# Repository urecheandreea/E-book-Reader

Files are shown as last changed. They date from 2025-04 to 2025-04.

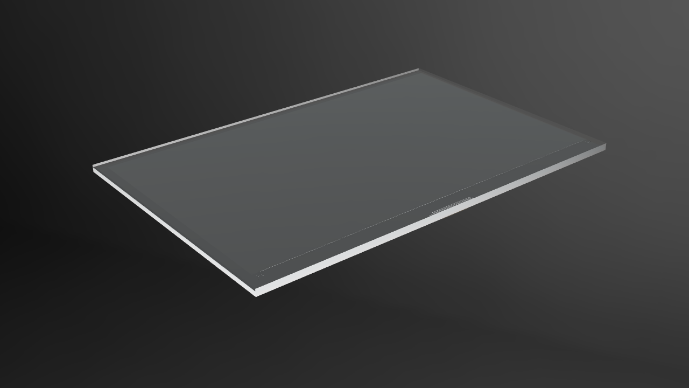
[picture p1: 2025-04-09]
Images/Display.png

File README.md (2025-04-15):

# E-book-Reader
## Hardware 
**OpenBook** is an open-source, portable e-reader powered by the **ESP32-C6-WROOM-1-N8** microcontroller.
### Microcontroller - **ESP32-C6-WROOM-1-N8**
  - 32-bit RISC-V @ 160 MHz
  - 8MB internal flash
  - Supports **Wi-Fi 6 (802.11ax)** and **Bluetooth 5.0 LE**
  - Interfaces used:
    - **SPI** (for E-Ink display, Flash, SD card)
    - **I2C** (for sensors and RTC)
    - **UART**, **GPIO**, **PWM**
### E-Ink Display
- **E-Ink screen** connected via SPI:
  - MOSI: GPIO18  
  - MISO: GPIO19  
  - CLK: GPIO20  
  - CS: GPIO21  
- Power is controlled via MOSFET (Q3 - S1B126DT1-GE3) to save energy.
- Display type selection is done via jumper (S11, P2).
##  Storage
- **MicroSD Card**
  - Connected via SPI (CS: GPIO9)
  - Used for storing files and data logging
- **NOR Flash – W25Q512JVEIQ**
  - 64MB external flash via SPI
##  Sensors
- **BME688** – Measures temperature, pressure, humidity, and air quality  
- **DS3231SN** – High-precision Real-Time Clock (RTC)  
- **MAX17048G+T10** – Battery fuel gauge (State of Charge)
- All sensors are connected via the **I2C** bus:
  - SDA: GPIO6  
  - SCL: GPIO7  
##  Power Management
- **USB-C connector**
  - Used for charging and possible data transfer
  - Includes CC identification and ESD protection
- **MCP73831** – LiPo battery charging IC
- **XC6220A331MR-G** – Low dropout regulators for 3.3V power
- EPD and I2C power rails are individually controlled via MOSFETs
- ESD protection on USB and SPI lines (USBLC6-2SC6Y, SD05B05V2L)
## Interfaces & Expandability
- **QWIIC / Stemma QT connector**
  - Easy expansion via plug-and-play I2C modules
- **Test Pads**
  - Breakout access to GPIO, UART, I2C for debugging
- **Control buttons**
  - RESET and BOOT
- **Status LEDs** for user feedback

## Power Consumption Summary
| Component | Active (mA) | Sleep (mA) | Notes |
|---|---|---|---|
| **ESP32-C6** | ~80–100 | ~0.02 | Depends on Wi-Fi & sleep mode |
| **E-Paper Display** | ~26 | ~0.01 | Only during refresh |
| **BME688 Sensor** | ~2.1 | ~0.15 | Sleep mode available |
| **RTC DS3231** | ~0.2 | ~0.2 | Constant low power |
| **MicroSD Card** | ~30–100 | ~0.2 | Depends on access frequency |
| **W25Q512JVEIQ Flash**| ~10–20 | ~0.01 | During SPI read/write |
## ESP32-C6 Pin Usage
| Component | ESP32-C6 Pin(s) | Interface | Purpose |
|---|---|---|---|
| E-Paper Display | GPIO7 (MOSI), GPIO6 (SCK), GPIO10 (CS), GPIO5 (DC), GPIO23 (RST), GPIO3 (BUSY) | SPI | Transfers image data to the display and controls its state |
| MicroSD Card | GPIO7 (MOSI), GPIO6 (SCK), GPIO4 (CS_SD), GPIO2 (MISO) | SPI | Allows storage and retrieval of e-book files |
| BME688 Sensor | GPIO21 (SDA), GPIO22 (SCL) | I2C | Reads temperature, humidity, pressure, and air quality |
| RTC Module (DS3231) | GPIO21 (SDA), GPIO22 (SCL), GPIO18 (RST), GPIO1 (32KHz, optional), GPIO0 (INT_RTC, optional) | I2C | Keeps track of time even when the ESP32 is off |
| NOR Flash (W25Q512J) | GPIO11 (CS_FLASH), GPIO6 (SCK), GPIO2 (MISO), GPIO7 (MOSI) | SPI | Additional non-volatile storage |
| Battery Fuel Gauge | GPIO21 (SDA), GPIO22 (SCL) | I2C | Monitors battery level and charge status |
| USB-C Connector | Via LDO regulator to 3.3V power rail | USB | Supplies power and programming interface for the ESP32-C6 |
| Control Buttons | GPIO9 (BOOT), GPIO15 (CHANGE), EN (RESET) | GPIO | User input for device interaction and hardware reset |

## Block Diagram
Diagram

## Bill Of Materials
| Component | Link | Datasheet |
|---|---|---|
| ESP32-C6-WROOM-1-N8 | [SnapEDA](https://www.snapeda.com/parts/ESP32-C6-WROOM-1-N8/Espressif+Systems/view-part/?ref=eda) | [Datasheet](https://www.snapeda.com/parts/ESP32-C6-WROOM-1-N8/Espressif%20Systems/datasheet/) |
| MCP73831T-2ACI/OT – PMIC | [SnapEDA](https://www.snapeda.com/parts/MCP73831T-2ACI/OT/Microchip/datasheet/) | [Datasheet](https://www.snapeda.com/parts/MCP73831T-2ACI/OT/Microchip/datasheet/) |
| MAX17048G+T10 – Fuel Gauge | [SnapEDA](https://www.snapeda.com/parts/MAX17048G+T10/Analog+Devices/view-part/?ref=eda) | [Datasheet](https://www.snapeda.com/parts/MAX17048G+T10/Analog%20Devices/datasheet/) |
| BME680 – Environmental Sensor | [SnapEDA](https://www.snapeda.com/parts/BME680/Bosch/view-part/?welcome=home) | [Datasheet](https://www.bosch-sensortec.com/media/boschsensortec/downloads/datasheets/bst-bme680-ds001.pdf) |
| DS3231SN – RTC | [SnapEDA](https://www.snapeda.com/parts/DS3231SN%23/Analog+Devices/view-part/?ref=eda) | [Datasheet](https://www.snapeda.com/parts/DS3231SN%23/Analog%20Devices/datasheet/) |
| W25Q512JVEIQ – SPI Flash | [SnapEDA](https://www.snapeda.com/parts/W25Q512JVEIQ/Winbond+Electronics/view-part/?ref=eda) | [Datasheet](https://www.winbond.com/resource-files/W25Q512JV%20SPI%20RevB%2006252019%20KMS.pdf) |
| QWIIC Connector | [SnapEDA](https://www.snapeda.com/parts/PRT-14417/SparkFun/view-part/) | [Datasheet](https://www.snapeda.com/parts/PRT-14417/SparkFun%20Electronics/datasheet/) |
| USB4110-GF-A – USB-C Connector | [ComponentSearchEngine](https://componentsearchengine.com/part-view/USB4110-GF-A/GCT%20(GLOBAL%20CONNECTOR%20TECHNOLOGY)) | [Datasheet](https://gct.co/files/drawings/usb4110.pdf) |
| FH34SRJ-24S-0.5SH – FFC Connector | [Mouser](https://ro.mouser.com/ProductDetail/Hirose-Connector/FH34SRJ-24S-0.5SH99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) | [Datasheet](https://www.snapeda.com/parts/FH34SRJ-24S-0.5SH(99)/Hirose%20Connector/datasheet/) |
| KP-1608SURCK – LED 0603 | [SnapEDA](https://www.snapeda.com/parts/KP-1608SURCK/Kingbright/view-part/?ref=search&t=LED%200603) | [Datasheet](https://www.snapeda.com/parts/KP-1608SURCK/Kingbright/datasheet/) |
| EVQPUJ02K – Custom Button | [Panasonic](https://industry.panasonic.com/global/en/products/control/switch/light-touch/number/evqpuj02k) | [Datasheet](https://industry.panasonic.com/global/en/downloads?tab=catalog&small_g_cd=203&part_no=EVQPUJ02K) |
| CPH3225A – RTC Crystal | [SnapEDA](https://www.snapeda.com/parts/CPH3225A/Seiko+Instruments/view-part/?ref=snap) | [Datasheet](https://www.snapeda.com/parts/CPH3225A/Seiko%20Instruments/datasheet/) |
| BD5229G-TR – Reset IC | [ComponentSearchEngine](https://componentsearchengine.com/part-view/BD5229G-TR/ROHM%20Semiconductor) | [Datasheet](https://fscdn.rohm.com/en/products/databook/datasheet/ic/power/voltage_detector/bd52xxg-e.pdf) |
| XC6220A331MR-G – LDO Regulator | [ComponentSearchEngine](https://componentsearchengine.com/part-view/XC6220A331MR-G/Torex) | [Datasheet](https://product.torexsemi.com/system/files/series/xc6220.pdf) |
| 744043680 – Inductor | [Mouser](https://ro.mouser.com/ProductDetail/Wurth-Elektronik/744043680?qs=PGXP4M47uW6VkZq%252BkzjrHA%3D%3D) | [Datasheet](https://www.we-online.com/components/products/datasheet/744043680.pdf) |
| SI1308EDL – MOSFET | [SnapEDA](https://www.snapeda.com/parts/SI1308EDL-T1-GE3/Vishay+Siliconix/view-part/?welcome=home&ref=eda) | [Datasheet](https://www.snapeda.com/parts/SI1308EDL-T1-GE3/Vishay%20Siliconix/datasheet/) |
| MBR0530 – Schottky Diode | [SnapEDA](https://www.snapeda.com/parts/MBR0530/Onsemi/view-part/?ref=snap) | [Datasheet](https://www.snapeda.com/parts/MBR0530/ON%20Semiconductor/datasheet/) |
| USBLC6-2SC6Y – ESD Protection | [SnapEDA](https://www.snapeda.com/parts/USBLC6-2SC6Y/STMicroelectronics/view-part/?welcome=home&ref=eda) | [Datasheet](https://www.snapeda.com/parts/USBLC6-2SC6Y/STMicroelectronics/datasheet/) |
| PGB1010603MR – TVS Protection | [SnapEDA](https://www.snapeda.com/parts/PGB1010603MR/Littelfuse/view-part/?ref=eda) | [Datasheet](https://www.snapeda.com/parts/PGB1010603MR/Littelfuse%20Inc./datasheet/) |
| 112A-TAAR-R03 – Pin Header | [Comet](https://store.comet.srl.ro/Catalogue/Product/43497/) | [Datasheet](https://www.snapeda.com/parts/112A-TAAR-R03/Attend/datasheet/) |
| 0402 Ceramic Capacitor | [Mouser](https://ro.mouser.com/c/passive-components/capacitors/ceramic-capacitors/?q=CC0402) | [Datasheet](https://componentsearchengine.com/Datasheets/2/CC0402MRX5R5BB106.pdf) |
| 0402 Resistor | [GrabCAD](https://grabcad.com/library/resistor-0402-1) | [Datasheet](https://www.yageo.com/upload/media/product/products/datasheet/rchip/PYu-RC_Group_51_RoHS_L_12.pdf) |
| TAJB475K025RNJ – 3528 Tantalum Cap | [SnapEDA](https://www.snapeda.com/parts/TAJB475K025RNJ/AVX%20Corporation/view-part/?ref=eda) | [Datasheet](https://s3.amazonaws.com/snapeda/datasheet/TAJB475K025RNJ_AVX.pdf) |
| SJ -SMD solder JUMPER | [GrabCAD](https://grabcad.com/library/solder-jumpers-1) | [DataSheet](https://www.farnell.com/datasheets/2813407.pdf) |
| PFMF.050.1-ESP32C6_VARISTORCN1812  | [Mouser](https://www.mouser.co.uk/ProductDetail/EPCOS-TDK/B72520T0350K062?qs=dEfas%2FXlABIszF52uu7vrg%3D%3D)| [DataSheet](https://www.tdk-electronics.tdk.com/inf/75/db/CTVS_14/Surge_protection_series.pdf)  | 

## Implementation Steps
Creating the schematic according to the diagram,Finding and loading 3D models for each component,Designing the PCB,Placing the components on the PCB,Routing,Creating ground planes, via-stitching,Meeting requirements (component names on top silkscreen, DRC clean, etc.),Creating the battery and display,Assembling everything into the enclosure.

I only approved the "SMD-Hole, Board Outline Clearance" errors, as this was previously accepted and specified.

## Issues encountered:
I had to manually add the 3D model for EACH component because I had problems and errors when trying to update the library (adding to the library wasn't working), which was extremely time-consuming.

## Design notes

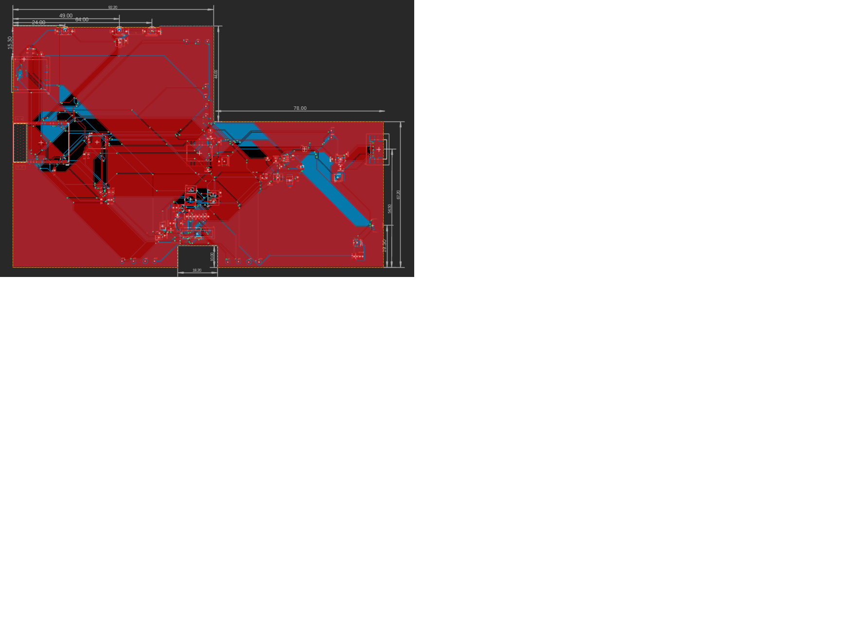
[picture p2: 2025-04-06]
Images/PCB1.png

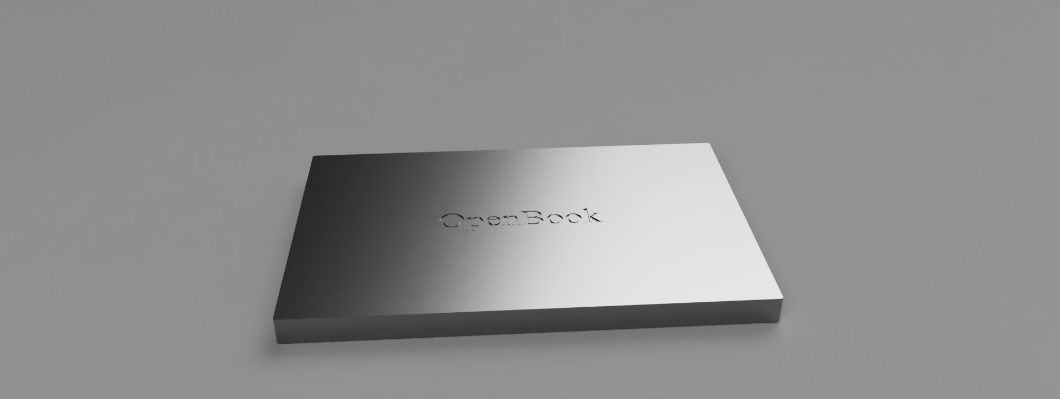
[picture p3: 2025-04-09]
Images/Render.png

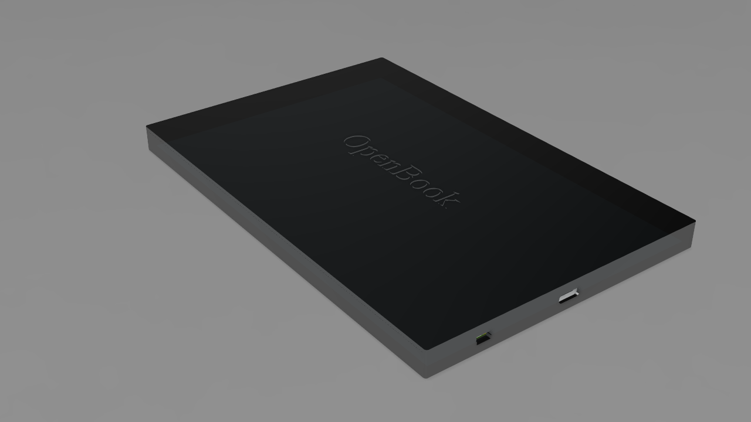
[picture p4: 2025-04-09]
Images/TopView.png

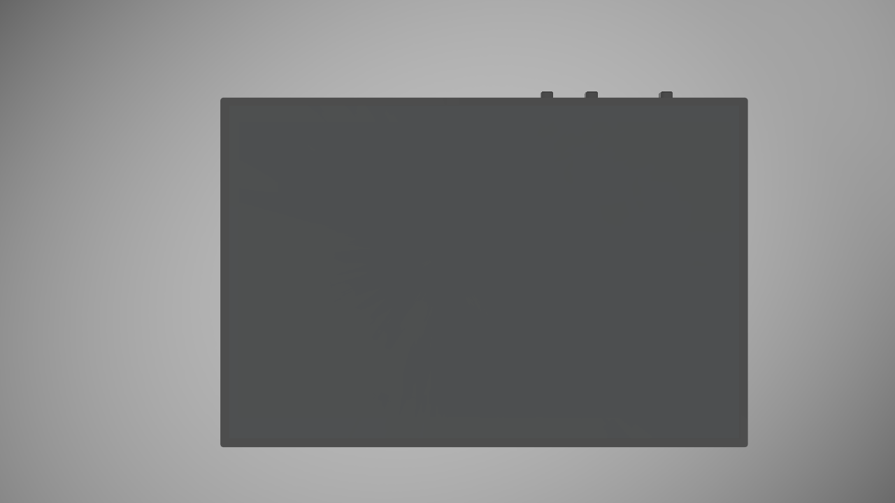
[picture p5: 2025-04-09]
Images/bottomView.png

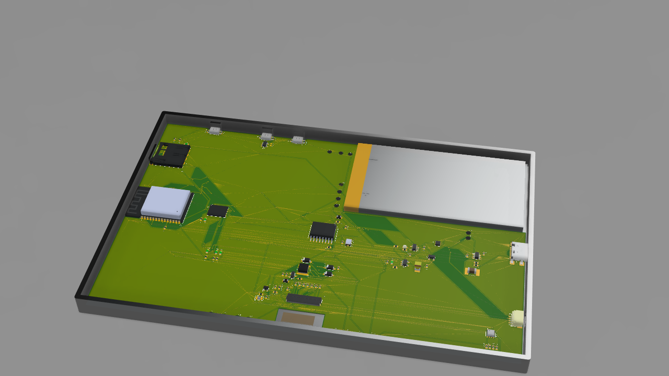
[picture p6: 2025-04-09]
Images/InteriorView.png

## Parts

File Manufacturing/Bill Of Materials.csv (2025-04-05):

Qty | Value | Device | Package | Parts | Description | ARROW_PART_NUMBER | ARROW_PRICE-STOCK | AVAILABILITY | CENTROID_NOT_SPECIFIED | CHECK_PRICES | COPYRIGHT | DATASHEET | DESCRIPTION | DIGIKEY_DESCRIPTION | DIGIKEY_PART_NUMBER | HEIGHT | LEAD_FREE | MANUFACTURER_NAME | MANUFACTURER_PART_NUMBER | MF | MFR_NAME | MOUSER_PART_NUMBER | MOUSER_PRICE-STOCK | MOUSER_TESTING_PART_NUMBER | MOUSER_TESTING_PRICE-STOCK | MP | MPN | PACKAGE | POPULARITY | PREFIX | PRICE | PROD_ID | PURCHASE-URL | ROHS | SNAPEDA_LINK | SPICEMODEL | SPICEPREFIX | TEMPERATURE_RANGE_HIGH | TEMPERATURE_RANGE_LOW | TP_SIGNAL_NAME | VALUE
1 |  | ADAFRUIT_LEDCHIP-LED0603 | ADAFRUIT_CHIP-LED0603 | CHG_LED | LED
1 |  | ESP32_WROVER_SPARKFUN-IC-POWER_MCP73831 | ESP32_WROVER_SPARKFUN-IC-POWER_SOT23-5 | MCP73831 | MCP73831T Li-Ion, Li-Pol Controller |  |  |  |  |  |  |  |  |  |  |  |  |  |  |  |  |  |  |  |  |  |  |  |  |  |  | IC-09995
1 |  | SJ | SJ | SJ1 | SMD solder JUMPER |  |  |  |  |  |  |  |  |  |  |  |  |  |  |  |  |  |  |  |  |  |  |  | 3
1 | 0.1uF/50V | ESP32_WROVER_EAGLE-LTSPICE_CC0402 | ESP32_WROVER_EAGLE-LTSPICE_C0402 | EPD_C5 | CAPACITOR, European symbol |  |  |  |  |  |  |  |  |  |  |  |  |  |  |  |  |  |  |  |  |  |  |  |  |  |  |  |  |  |  | NONE | C
1 | 0.47 | ESP32_WROVER_EAGLE-LTSPICE_RR0402 | ESP32_WROVER_EAGLE-LTSPICE_R0402 | R3 | RESISTOR, European symbol |  |  |  |  |  |  |  |  |  |  |  |  |  |  |  |  |  |  |  |  |  |  |  |  |  |  |  |  |  |  | NONE | R
1 | 100k | ESP32_WROVER_EAGLE-LTSPICE_RR0402 | ESP32_WROVER_EAGLE-LTSPICE_R0402 | R1_PWRUSB | RESISTOR, European symbol |  |  |  |  |  |  |  |  |  |  |  |  |  |  |  |  |  |  |  |  |  |  |  |  |  |  |  |  |  |  | NONE | R
6 | 100nF | EAGLE-LTSPICE_CC0402 | EAGLE-LTSPICE_C0402 | C1, C2, C6, C9, C10, C_DELAY | CAPACITOR, European symbol |  |  |  |  |  |  |  |  |  |  |  |  |  |  |  |  |  |  |  |  |  |  |  |  |  |  |  |  |  |  | NONE | C
2 | 100nF | ESP32_WROVER_EAGLE-LTSPICE_CC0402 | ESP32_WROVER_EAGLE-LTSPICE_C0402 | C4_USB, C8 | CAPACITOR, European symbol |  |  |  |  |  |  |  |  |  |  |  |  |  |  |  |  |  |  |  |  |  |  |  |  |  |  |  |  |  |  | NONE | C
1 | 100uF TANT | RCL_CPOL-EUCT3528 | RCL_CT3528 | C3 | POLARIZED CAPACITOR, European symbol |  |  |  |  |  |  |  |  |  |  |  |  |  |  |  |  |  |  |  |  |  |  |  | 0 |  |  |  |  |  |  |  | C
16 | 10K | ESP32_WROVER_EAGLE-LTSPICE_RR0402 | ESP32_WROVER_EAGLE-LTSPICE_R0402 | R1, R1_PINH, R1_PINH1, R2-PINH, R2-PINH1, R4, R5, R6, R7, R8, R9, R10, R_BOOT, R_CHANGE, R_CL1, R_RESET | RESISTOR, European symbol |  |  |  |  |  |  |  |  |  |  |  |  |  |  |  |  |  |  |  |  |  |  |  |  |  |  |  |  |  |  | NONE | R
1 | 10uF | ESP32_WROVER_EAGLE-LTSPICE_CC0402 | ESP32_WROVER_EAGLE-LTSPICE_C0402 | C7 | CAPACITOR, European symbol |  |  |  |  |  |  |  |  |  |  |  |  |  |  |  |  |  |  |  |  |  |  |  |  |  |  |  |  |  |  | NONE | C
1 | 112A-TAAR-R03_ATTEND | 112A-TAAR-R03_ATTEND | 112ATAARR03ATTEND | J4 | Micro SD Card Socket, Push-Push Type, Top Mount, SMT, H=1.83mm, 10u |  |  |  |  |  |  |  | Micro SD Card Socket | Push-Push Type | Top Mount | SMT | H=1.83mm | 10u |  |  | 1.9mm |  | ATTEND | 112A-TAAR-R03 ATTEND
1 | 15 | ESP32_WROVER_EAGLE-LTSPICE_RR0402 | ESP32_WROVER_EAGLE-LTSPICE_R0402 | R_CAPACITOR | RESISTOR, European symbol |  |  |  |  |  |  |  |  |  |  |  |  |  |  |  |  |  |  |  |  |  |  |  |  |  |  |  |  |  |  | NONE | R
1 | 1uF | EAGLE-LTSPICE_CC0402 | EAGLE-LTSPICE_C0402 | C5 | CAPACITOR, European symbol |  |  |  |  |  |  |  |  |  |  |  |  |  |  |  |  |  |  |  |  |  |  |  |  |  |  |  |  |  |  | NONE | C
9 | 1uF/50V | ESP32_WROVER_EAGLE-LTSPICE_CC0402 | ESP32_WROVER_EAGLE-LTSPICE_C0402 | EPD_C1, EPD_C2, EPD_C6, EPD_C7, EPD_C8, EPD_C9, EPD_C10, EPD_C11, EPD_C12 | CAPACITOR, European symbol |  |  |  |  |  |  |  |  |  |  |  |  |  |  |  |  |  |  |  |  |  |  |  |  |  |  |  |  |  |  | NONE | C
1 | 2.2 | ESP32_WROVER_EAGLE-LTSPICE_RR0402 | ESP32_WROVER_EAGLE-LTSPICE_R0402 | R2 | RESISTOR, European symbol |  |  |  |  |  |  |  |  |  |  |  |  |  |  |  |  |  |  |  |  |  |  |  |  |  |  |  |  |  |  | NONE | R
1 | 200 | ESP32_WROVER_EAGLE-LTSPICE_RR0402 | ESP32_WROVER_EAGLE-LTSPICE_R0402 | R1_BAT | RESISTOR, European symbol |  |  |  |  |  |  |  |  |  |  |  |  |  |  |  |  |  |  |  |  |  |  |  |  |  |  |  |  |  |  | NONE | R
2 | 20V/4.2A/52mO/1.4W | ESP32_WROVER_SPARKFUN-DISCRETESEMI_MOSFET_PCH-DMG2305UX-7 | ESP32_WROVER_SPARKFUN-DISCRETESEMI_SOT23-3 | Q1, Q2 | P-channel MOSFETs |  |  |  |  |  |  |  |  |  |  |  |  |  |  |  |  |  |  |  |  |  |  |  |  |  |  | TRAN-14388 |  |  |  |  |  |  |  |  | 20V/4.2A/52mO/1.4W
1 | 2K | ESP32_WROVER_EAGLE-LTSPICE_RR0402 | ESP32_WROVER_EAGLE-LTSPICE_R0402 | R2_BAT | RESISTOR, European symbol |  |  |  |  |  |  |  |  |  |  |  |  |  |  |  |  |  |  |  |  |  |  |  |  |  |  |  |  |  |  | NONE | R
5 | 4.7uF | EAGLE-LTSPICE_CC0402 | EAGLE-LTSPICE_C0402 | C1_BAT, C1_BAT1, C1_BAT2, C2_BAT, C5_USB | CAPACITOR, European symbol |  |  |  |  |  |  |  |  |  |  |  |  |  |  |  |  |  |  |  |  |  |  |  |  |  |  |  |  |  |  | NONE | C
1 | 4.7uF/25V | ESP32_WROVER_EAGLE-LTSPICE_CC0402 | ESP32_WROVER_EAGLE-LTSPICE_C0402 | C4 | CAPACITOR, European symbol |  |  |  |  |  |  |  |  |  |  |  |  |  |  |  |  |  |  |  |  |  |  |  |  |  |  |  |  |  |  | NONE | C
2 | 5k1 | ESP32_WROVER_EAGLE-LTSPICE_RR0402 | ESP32_WROVER_EAGLE-LTSPICE_R0402 | R2-USB, R2-USB1 | RESISTOR, European symbol |  |  |  |  |  |  |  |  |  |  |  |  |  |  |  |  |  |  |  |  |  |  |  |  |  |  |  |  |  |  | NONE | R
1 | 68uH | 744043680IND_4828-WE-TPC_WRE | IND_4828-WE-TPC_WRE | L1 |  |  |  |  |  |  | Copyright (C) 2024 Ultra Librarian. All rights reserved. |  |  |  |  |  |  |  | 744043680 |  | Wurth Electronics
1 | BD5229G-TR | BD5229G-TR | SOT95P280X125-5N | IC1 | Voltage Detector with Adjustable Delay Time: CMOS processes are utilized to develop high precision, low current consumption CMOS reset ICs that allow arbitrary setting of the delay time. The extensive lineup includes both Nch Open Drain and CMOS output types in a wide range of detection voltages (from 2.3V to 6.0V, in 0.1V steps), enabling selection of the ideal solution based on customer requirements. In addition, the entire series is of course both lead-free and RoHS-compliant. |  |  |  |  |  |  |  | Voltage Detector with Adjustable Delay Time: CMOS processes are utilized to develop high precision | low current consumption CMOS reset ICs that allow arbitrary setting of the delay time. The extensive lineup includes both Nch Open Drain and CMOS output types in a wide range of detection voltages (from 2.3V to 6.0V | in 0.1V steps) | enabling selection of the ideal solution based on customer requirements. In addition | the entire series is of course both lead-free and RoHS-compliant. |  |  | 1.25mm |  | ROHM Semiconductor | BD5229G-TR |  |  | 755-BD5229G-TR | https://www.mouser.co.uk/ProductDetail/ROHM-Semiconductor/BD5229G-TR?qs=4kLU8WoGk0vvnhrrYwdszw%3D%3D
1 | BME688 | ESP32_WROVER_BME680_BME680 | ESP32_WROVER_BME680_PSON80P300X300X100-8N | SENSOR2 | Integrated Environmental Unit |  |  | Unavailable |  |  |  |  | Integrated Environmental Unit |  |  |  |  |  |  | Bosch Sensortec |  |  |  |  |  | BME680 |  | LGA-8 Bosch Tools |  |  | None
1 | BOOT_BUTTON | BUTTON_CUSYOMV1 | MYBUTTON | BOOT_BUTTON
1 | CHANGE_BUTTON | BUTTON_CUSYOMV1 | MYBUTTON | CHANGE_BUTTON
1 | CPH3225A | CPH3225A | CAPCP3225X100N | C10_SUPERCAP | Cap 0.011F 3.3V 1210 Flat Check availability |  |  | Not in stock |  | https://www.snapeda.com/parts/CPH3225A/Seiko+Instruments/view-part/?ref=eda |  |  | 11 mF (EDLC) Supercapacitor 3.3 V 1210 (3225 Metric) - - |  |  |  |  |  |  | Seiko Instruments |  |  |  |  |  | CPH3225A |  | 1210 Seiko |  |  | None |  | https://www.snapeda.com/api/url_track_click_mouser/?unipart_id=562593&manufacturer=Seiko Instruments&part_name=CPH3225A&search_term=None |  | https://www.snapeda.com/parts/CPH3225A/Seiko+Instruments/view-part/?ref=snap
1 | DS3231SN# | DS3231SN# | SOIC127P1032X265-16N | U3 | Real Time Clock Serial 16-Pin SOIC W T/R Check availability |  |  | In Stock |  | https://www.snapeda.com/parts/DS3231SN%23/Analog+Devices/view-part/?ref=eda |  |  | Extremely Accurate I²C-Integrated RTC/TCXO/Crystal |  |  |  |  |  |  | Analog Devices |  |  |  |  |  | DS3231SN# |  | SOIC-16 Maxim |  |  | None |  | https://www.snapeda.com/api/url_track_click_mouser/?unipart_id=99048&manufacturer=Analog Devices&part_name=DS3231SN#&search_term=None |  | https://www.snapeda.com/parts/DS3231SN%23/Analog+Devices/view-part/?ref=snap
1 | ESP32-C6-WROOM-1-N8 | ESP32-C6-WROOM-1-N8 | XCVR_ESP32-C6-WROOM-1-N8 | U2 | Check availability |  |  | In Stock |  | https://www.snapeda.com/parts/ESP32-C6-WROOM-1-N8/Espressif+Systems/view-part/?ref=eda |  |  | Multiprotocol Modules ESP32-C6 module | Wi-Fi 6 in 2.4 GHz band | Bluetooth 5 | Zigbee 3.0 and Thread. ESP34-WROOM Compatible - ENGINEERING SAMPLE |  |  |  |  |  |  | Espressif Systems |  |  |  |  |  | ESP32-C6-WROOM-1-N8 |  | None |  |  | None |  |  |  | https://www.snapeda.com/parts/ESP32-C6-WROOM-1-N8/Espressif+Systems/view-part/?ref=snap
1 | ESP32C6_VARISTORCN1812 | ESP32C6_VARISTORCN1812 | ESP32C6_VARISTOR_CT/CN1812 | PFMF.050.1 | VARISTOR |  |  |  |  |  |  |  |  |  |  |  |  |  |  |  |  |  |  |  |  |  |  |  | 0
1 | ESP32_WROVER_AVX---SD0805S020S1R0_AVX_SD0805S020S1R0_0_0AVX_SD0805S020S1R0_0_0 | ESP32_WROVER_AVX---SD0805S020S1R0_AVX_SD0805S020S1R0_0_0AVX_SD0805S020S1R0_0_0 | ESP32_WROVER_AVX---SD0805S020S1R0_AVX_SD0805S020S1R0_0 | D2 | Schottky Barrier Rectifier Diode |  |  |  | No |  |  | http://datasheets.avx.com/schottky.pdf |  | DIODE SCHOTTKY 20V 1A 0805 | 478-7800-1-ND |  | yes |  |  | AVX |  | 581-SD0805S020S1R0 |  |  |  |  |  | 0805 (2012 metric) |  | D |  |  |  | yes |  |  |  | +125°C | -55°C
1 | FH34SRJ-24S-0.5SH_99_ | FH34SRJ-24S-0.5SH_99_ | FH34SRJ24S05SH99 | J1 | (0.50mm) Surface Mount, Right Angle |  |  |  |  |  |  |  | 24 Position FFC | FPC Connector Contacts | (0.50mm) Surface Mount | Right Angle |  |  | 1.1mm |  | Hirose | FH34SRJ-24S-0.5SH(99) |  |  | 798-FH34SRJ24S05SH99 | https://www.mouser.co.uk/ProductDetail/Hirose-Connector/FH34SRJ-24S-0.5SH99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
1 | MAX17048G+T10 | MAX17048G+T10 | SON50P200X200X80-9N | U4 | Check availability |  |  | In Stock |  | https://www.snapeda.com/parts/MAX17048G+T10/Analog+Devices/view-part/?ref=eda |  |  | 3µA 1-Cell/2-Cell Fuel Gauge with ModelGauge |  |  |  |  |  |  | Analog Devices |  |  |  |  |  | MAX17048G+T10 |  | TDFN-8 Maxim |  |  | None |  | https://www.snapeda.com/api/url_track_click_mouser/?unipart_id=329239&manufacturer=Analog Devices&part_name=MAX17048G+T10&search_term=None |  | https://www.snapeda.com/parts/MAX17048G+T10/Analog+Devices/view-part/?ref=snap
3 | MBR0530 | MBR0530 | SOD3716X135N | D3, D4, D5 | ON SEMICONDUCTOR - MBR0530 - DIODE, SCHOTTKY, 0.5A, 30V, SOD-123 |  |  | In Stock |  | https://www.snapeda.com/parts/MBR0530/Onsemi/view-part/?ref=eda |  |  | Diode Schottky 30 V 500mA Surface Mount SOD-123 |  |  |  |  |  |  | ON Semiconductor |  |  |  |  |  | MBR0530 |  | SOD-123-2 ON Semiconductor |  |  | None |  | https://www.snapeda.com/api/url_track_click_mouser/?unipart_id=179458&manufacturer=ON Semiconductor&part_name=MBR0530&search_term=None |  | https://www.snapeda.com/parts/MBR0530/Onsemi/view-part/?ref=snap
6 | PGB1010603MR | PGB1010603MR | DIOC1608X36N | D6, D8, D9, D10, D11, D12 | Check availability |  |  | In Stock |  | https://www.snapeda.com/parts/PGB1010603MR/Littelfuse/view-part/?ref=eda |  |  | 150V (Typ) Clamp - Ipp Tvs Diode Surface Mount 0603 (1608 Metric) |  |  |  |  |  |  | Littelfuse Inc. |  |  |  |  |  | PGB1010603MR |  | 0603 Littelfuse Inc. |  |  | None |  | https://www.snapeda.com/api/url_track_click_mouser/?unipart_id=5659453&manufacturer=Littelfuse Inc.&part_name=PGB1010603MR&search_term=None |  | https://www.snapeda.com/parts/PGB1010603MR/Littelfuse/view-part/?ref=snap
1 | QWIIC_RIGHT_ANGLE | QWIIC_CONNECTORJS-1MM | JST04_1MM_RA | J3 | SparkFun I2C Standard Qwiic Connector |  |  |  |  |  |  |  |  |  |  |  |  |  |  |  |  |  |  |  |  |  |  |  |  |  |  | CONN-13694 |  |  |  |  |  |  |  |  | QWIIC_RIGHT_ANGLE
1 | RESET_BUTTON | BUTTON_CUSYOMV1 | MYBUTTON | RESET_BUTTON
1 | SAMACSYS_PARTS_USB4110-GF-A | SAMACSYS_PARTS_USB4110-GF-A | SAMACSYS_PARTS_USB4110GFA | J2 | CONN USB 2.0 TYPE-C R/A SMT |  |  |  |  |  |  |  | CONN USB 2.0 TYPE-C R/A SMT |  |  | 3.26mm |  | GCT (GLOBAL CONNECTOR TECHNOLOGY) | USB4110-GF-A |  |  | 640-USB4110-GF-A | https://www.mouser.co.uk/ProductDetail/GCT/USB4110-GF-A?qs=KUoIvG%2F9IlYiZvIXQjyJeA%3D%3D
1 | SD0805S020S1R0 | ESP32_WROVER_AVX---SD0805S020S1R0_AVX_SD0805S020S1R0_0_0AVX_SD0805S020S1R0_0_0 | ESP32_WROVER_AVX---SD0805S020S1R0_AVX_SD0805S020S1R0_0 | D7 | Schottky Barrier Rectifier Diode |  |  |  | No |  |  | http://datasheets.avx.com/schottky.pdf |  | DIODE SCHOTTKY 20V 1A 0805 | 478-7800-1-ND |  | yes |  |  | AVX |  | 581-SD0805S020S1R0 |  |  |  |  |  | 0805 (2012 metric) |  | D |  |  |  | yes |  |  |  | +125°C | -55°C
1 | SI1308EDL-T1-GE3 | SI1308EDL-T1-GE3 | SOT65P210X110-3N | Q3 | MOSFET N-Ch 30V 1.5A TrenchFET SC70 Vishay Si1308EDL-T1-GE3 N-channel MOSFET Transistor, 1.5 A, 30 V, 3-Pin SC-70 |  |  | In Stock |  | https://www.snapeda.com/parts/SI1308EDL-T1-GE3/Vishay+Siliconix/view-part/?ref=eda |  |  | Si1308EDL-T1-GE3 N-channel MOSFET Transistor | 1.5 A | 30 V | 3-Pin SC-70 | Siliconix / Vishay SI1308EDL-T1-GE3 |  |  |  |  |  |  | Vishay Siliconix |  |  |  |  |  | SI1308EDL-T1-GE3 |  | SOT-323 Vishay Semiconductor |  |  | None |  | https://www.snapeda.com/api/url_track_click_mouser/?unipart_id=274603&manufacturer=Vishay Siliconix&part_name=SI1308EDL-T1-GE3&search_term=None |  | https://www.snapeda.com/parts/SI1308EDL-T1-GE3/Vishay+Siliconix/view-part/?ref=snap
17 | TPTP20R | TPTP20R | TP20R | TP1, TP2, TP3, TP4, TP5, TP6, TP7, TP8, TP9, TP10, TP11, TP12, TP13, TP14, TP15, TP16, TP17 | Test pad |  |  |  |  |  |  |  |  |  |  |  |  |  |  |  |  |  |  |  |  |  |  |  | 2
1 | USBLC6-2SC6Y | USBLC6-2SC6Y | SOT95P280X145-6N | D1 | Low Cap. ESD Protection Auto SOT-23-6 STMicroelectronics USBLC6-2SC6Y, Dual Uni-Directional TVS Diode Array, 6-Pin SOT-23 |  |  | In Stock |  | https://www.snapeda.com/parts/USBLC6-2SC6Y/STMicroelectronics/view-part/?ref=eda |  |  | 17V Clamp 5A (8/20µs) Ipp Tvs Diode Surface Mount SOT-23-6 |  |  |  |  |  |  | STMicroelectronics |  |  |  |  |  | USBLC6-2SC6Y |  | SOT-23-6 STMicroelectronics |  |  | None |  |  |  | https://www.snapeda.com/parts/USBLC6-2SC6Y/STMicroelectronics/view-part/?ref=snap
1 | W25Q512JVEIQ | W25Q512JVEIQ | SON127P600X800X80-9N | U1 | Check availability |  |  | In Stock |  | https://www.snapeda.com/parts/W25Q512JVEIQ/Winbond+Electronics/view-part/?ref=eda |  |  | FLASH - NOR Memory IC 512Mb (64M x 8) SPI - Quad I/O 133 MHz 8-WSON (8x6) |  |  |  |  |  |  | Winbond Electronics |  |  |  |  |  | W25Q512JVEIQ |  | Package |  |  | None |  |  |  | https://www.snapeda.com/parts/W25Q512JVEIQ/Winbond+Electronics/view-part/?ref=snap
1 | XC6220A331MR-G | XC6220A331MR-G | SOT95P280X120-5N | IC4 | LDO Voltage Regulators |  |  |  |  |  |  |  | LDO Voltage Regulators |  |  | 1.2mm |  | Torex | XC6220A331MR-G |  |  | 865-XC6220A331MR-G | https://www.mouser.co.uk/ProductDetail/Torex-Semiconductor/XC6220A331MR-G?qs=AsjdqWjXhJ8ZSWznL1J0gg%3D%3D

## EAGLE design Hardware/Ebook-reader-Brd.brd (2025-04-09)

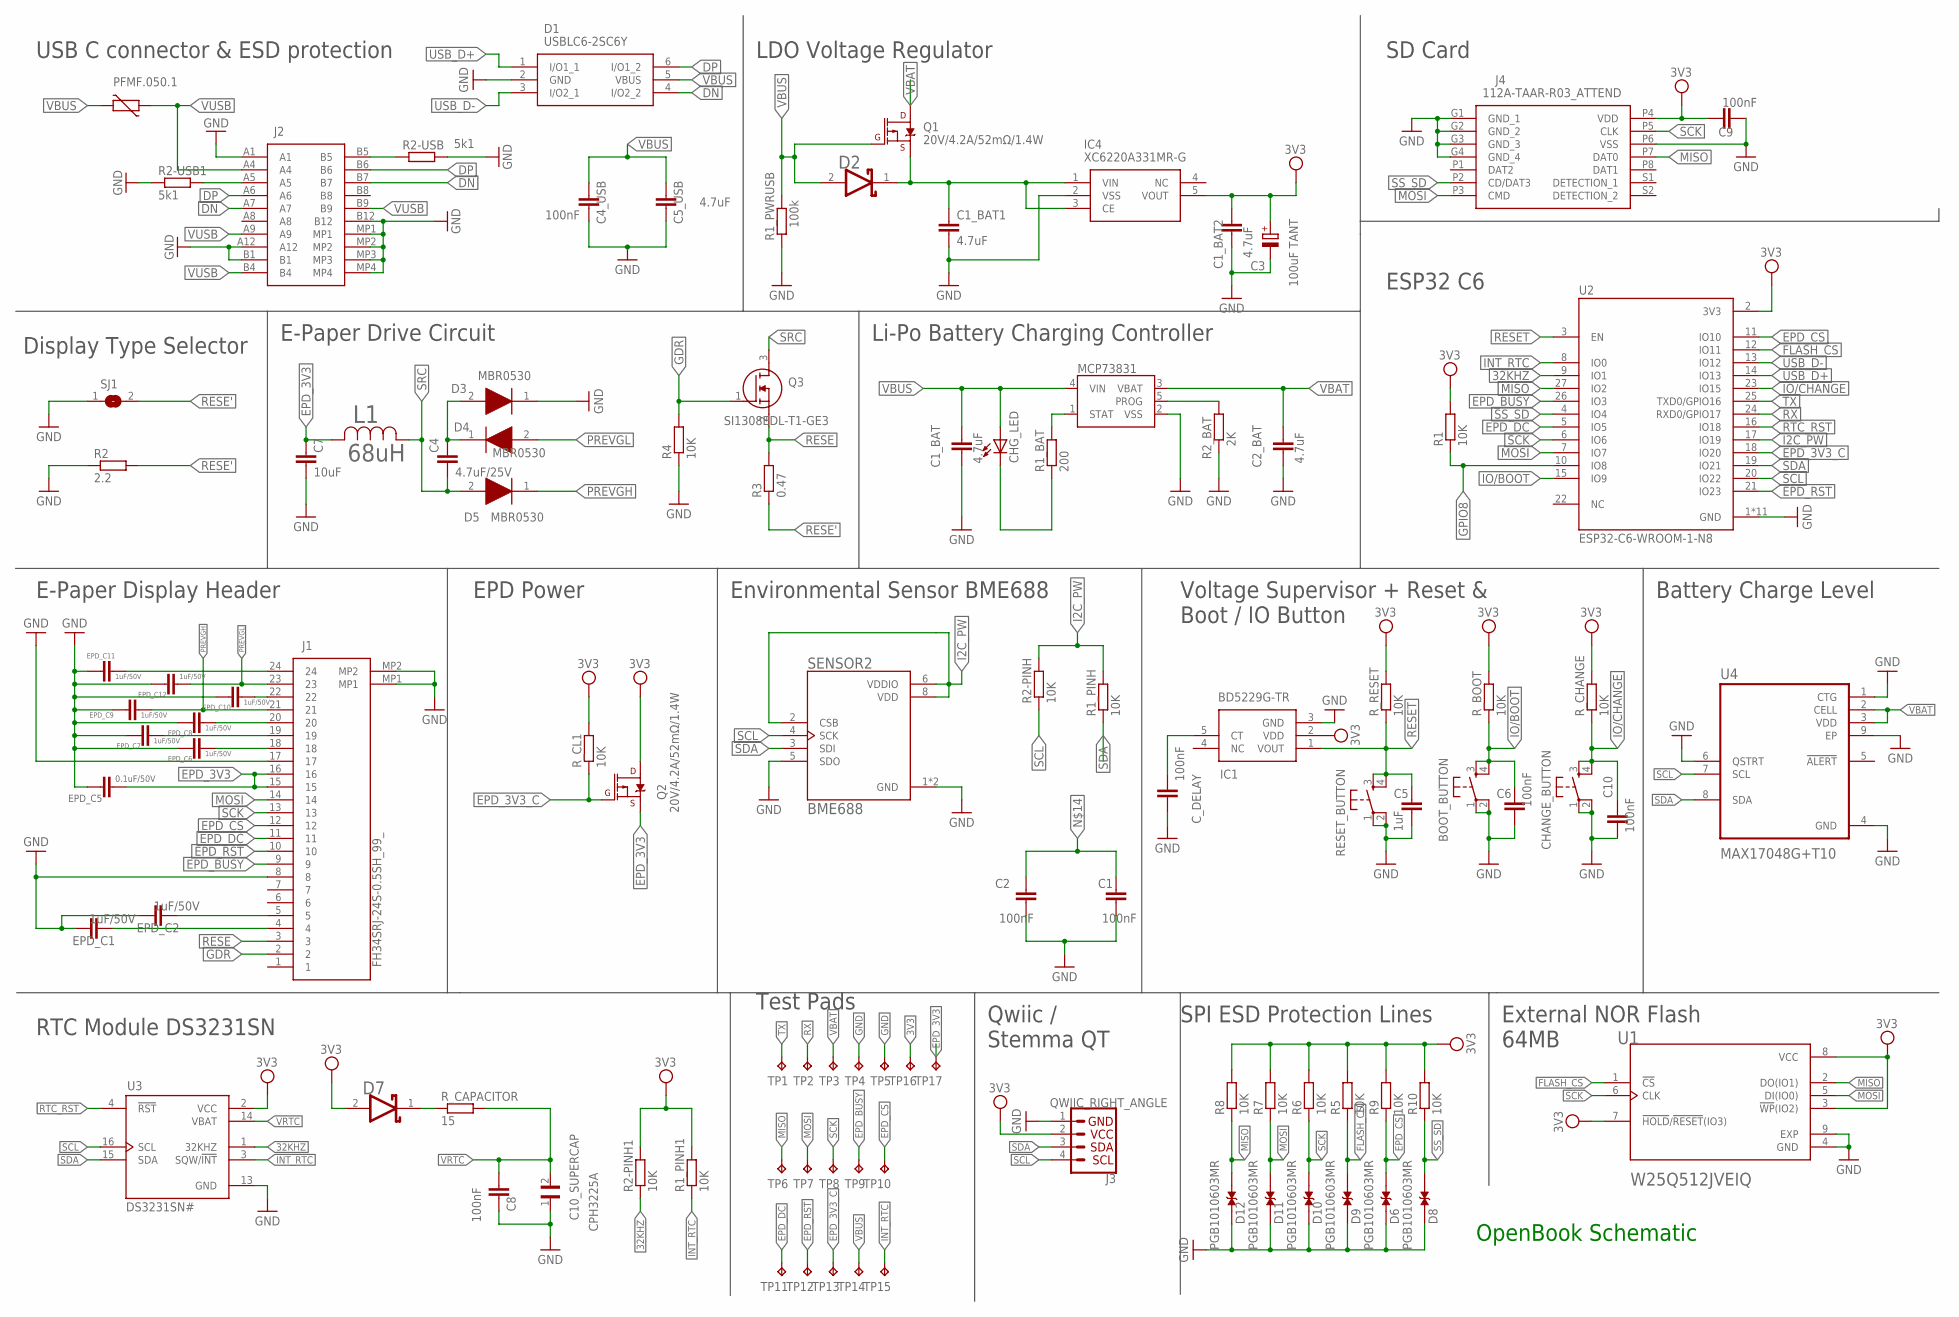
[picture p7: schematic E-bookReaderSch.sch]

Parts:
BOOT_BUTTON: BOOT_BUTTON; MYBUTTON
C1, C2, C6, C9, C10: 100nF; EAGLE-LTSPICE_C0402
C1_BAT, C1_BAT1, C1_BAT2, C2_BAT, C5_USB: 4.7uF; EAGLE-LTSPICE_C0402
C3: 100uF TANT; RCL_CT3528
C4: 4.7uF/25V; ESP32_WROVER_EAGLE-LTSPICE_C0402
C4_USB, C8: 100nF; ESP32_WROVER_EAGLE-LTSPICE_C0402
C5: 1uF; EAGLE-LTSPICE_C0402
C7: 10uF; ESP32_WROVER_EAGLE-LTSPICE_C0402
C10_SUPERCAP: CPH3225A; CAPCP3225X100N
CHANGE_BUTTON: CHANGE_BUTTON; MYBUTTON
CHG_LED: ADAFRUIT_LEDCHIP-LED0603; ADAFRUIT_CHIP-LED0603
C_DELAY: 100nF; EAGLE-LTSPICE_C0402
D1: USBLC6-2SC6Y; SOT95P280X145-6N
D2: ESP32_WROVER_AVX---SD0805S020S1R0_AVX_SD0805S020S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; ESP32_WROVER_AVX---SD0805S020S1R0_AVX_SD0805S020S1R0_0
D3, D4, D5: MBR0530; SOD3716X135N
D6, D8, D9, D10, D11, D12: PGB1010603MR; DIOC1608X36N
D7: SD0805S020S1R0; ESP32_WROVER_AVX---SD0805S020S1R0_AVX_SD0805S020S1R0_0
EPD_C1, EPD_C2, EPD_C6, EPD_C7, EPD_C8, EPD_C9, EPD_C10, EPD_C11, EPD_C12: 1uF/50V; ESP32_WROVER_EAGLE-LTSPICE_C0402
EPD_C5: 0.1uF/50V; ESP32_WROVER_EAGLE-LTSPICE_C0402
IC1: BD5229G-TR; SOT95P280X125-5N
IC4: XC6220A331MR-G; SOT95P280X120-5N
J1: FH34SRJ-24S-0.5SH_99_; FH34SRJ24S05SH99
J2: SAMACSYS_PARTS_USB4110-GF-A; SAMACSYS_PARTS_USB4110GFA
J3: QWIIC_RIGHT_ANGLE; JST04_1MM_RA
J4: 112A-TAAR-R03_ATTEND; 112ATAARR03ATTEND
L1: 68uH; IND_4828-WE-TPC_WRE
MCP73831: ESP32_WROVER_SPARKFUN-IC-POWER_MCP73831; ESP32_WROVER_SPARKFUN-IC-POWER_SOT23-5
PFMF.050.1: ESP32C6_VARISTORCN1812; ESP32C6_VARISTOR_CT/CN1812
Q1, Q2: 20V/4.2A/52mΩ/1.4W; ESP32_WROVER_SPARKFUN-DISCRETESEMI_SOT23-3
Q3: SI1308EDL-T1-GE3; SOT65P210X110-3N
R1, R1_PINH, R1_PINH1, R2-PINH, R2-PINH1, R4, R5, R6, R7, R8, R9, R10: 10K; ESP32_WROVER_EAGLE-LTSPICE_R0402
R1_BAT: 200; ESP32_WROVER_EAGLE-LTSPICE_R0402
R1_PWRUSB: 100k; ESP32_WROVER_EAGLE-LTSPICE_R0402
R2: 2.2; ESP32_WROVER_EAGLE-LTSPICE_R0402
R2-USB, R2-USB1: 5k1; ESP32_WROVER_EAGLE-LTSPICE_R0402
R2_BAT: 2K; ESP32_WROVER_EAGLE-LTSPICE_R0402
R3: 0.47; ESP32_WROVER_EAGLE-LTSPICE_R0402
RESET_BUTTON: RESET_BUTTON; MYBUTTON
R_BOOT: 10K; ESP32_WROVER_EAGLE-LTSPICE_R0402
R_CAPACITOR: 15; ESP32_WROVER_EAGLE-LTSPICE_R0402
R_CHANGE: 10K; ESP32_WROVER_EAGLE-LTSPICE_R0402
R_CL1: 10K; ESP32_WROVER_EAGLE-LTSPICE_R0402
R_RESET: 10K; ESP32_WROVER_EAGLE-LTSPICE_R0402
SENSOR2: BME688; ESP32_WROVER_BME680_PSON80P300X300X100-8N
SJ1: SJ
TP1, TP2, TP3, TP4, TP5, TP6, TP7, TP8, TP9, TP10, TP11, TP12, TP13, TP14, TP15, TP16, TP17: TPTP20R; TP20R
U1: W25Q512JVEIQ; SON127P600X800X80-9N
U2: ESP32-C6-WROOM-1-N8; XCVR_ESP32-C6-WROOM-1-N8
U3: DS3231SN#; SOIC127P1032X265-16N
U4: MAX17048G+T10; SON50P200X200X80-9N

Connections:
3V3: C1_BAT2.1, C3.+, C9.1, D7.2 (ANODE), IC1.2 (VDD), IC4.5 (VOUT), J3.2, J4.P4 (VDD), Q2.3 (D), R1.2, R1_PINH1.2, R2-PINH1.2, R5.2, R6.2, R7.2, R8.2, R9.2, R10.2, R_BOOT.2, R_CHANGE.2, R_CL1.2, R_RESET.2, TP16.TP, U1.3 (!WP!(IO2)), U1.7 (!HOLD!/!RESET!(IO3)), U1.8 (VCC), U2.2 (3V3), U3.2 (VCC)
32KHZ: R2-PINH1.1, U2.9 (IO1), U3.1 (32KHZ)
DN: D1.4 (I/O2_2), J2.A7, J2.B7
DP: D1.6 (I/O1_2), J2.A6, J2.B6
EPD_3V3: C7.1, EPD_C5.1, J1.15, J1.16, L1.2, Q2.2 (S), TP17.TP
EPD_3V3_C: Q2.1 (G), R_CL1.1, TP13.TP, U2.18 (IO20)
EPD_BUSY: J1.9, TP9.TP, U2.26 (IO3)
EPD_CS: D6.2, J1.12, R9.1, TP10.TP, U2.11 (IO10)
EPD_DC: J1.11, TP11.TP, U2.5 (IO5)
EPD_RST: J1.10, TP12.TP, U2.21 (IO23)
FLASH_CS: D9.2, R5.1, U1.1 (!CS), U2.12 (IO11)
GDR: J1.2, Q3.1 (G), R4.2
GND: BOOT_BUTTON.1, BOOT_BUTTON.2, C1.2, C1_BAT.2, C1_BAT1.2, C1_BAT2.2, C2.2, C2_BAT.2, C3.-, C4_USB.2, C5.2, C5_USB.2, C6.2, C7.2, C8.2, C9.2, C10.2, C10_SUPERCAP.1, CHANGE_BUTTON.1, CHANGE_BUTTON.2, C_DELAY.2, D1.2 (GND), D3.1 (K), D6.1, D8.1, D9.1, D10.1, D11.1, D12.1, EPD_C1.2, EPD_C2.2, EPD_C5.2, EPD_C6.2, EPD_C7.2, EPD_C8.2, EPD_C9.2, EPD_C10.2, EPD_C11.2, EPD_C12.2, IC1.3 (GND), IC4.2 (VSS), J1.8, J1.17, J1.MP1, J1.MP2, J2.A1, J2.A12, J2.B1, J2.B12, J2.MP1, J2.MP2, J2.MP3, J2.MP4, J3.1, J4.G1 (GND_1), J4.G2 (GND_2), J4.G3 (GND_3), J4.G4 (GND_4), J4.P6 (VSS), MCP73831.2 (VSS), R1_PWRUSB.1, R2.1, R2-USB.2, R2-USB1.1, R2_BAT.1, R4.1, RESET_BUTTON.1, RESET_BUTTON.2, SENSOR2.1 (GND), SENSOR2.5 (SDO), SENSOR2.7 (GND), SJ1.1, TP4.TP, TP5.TP, U1.4 (GND), U1.9 (EXP), U2.1 (GND), U2.28 (GND), U2.29_1 (GND), U2.29_2 (GND), U2.29_3 (GND), U2.29_4 (GND), U2.29_5 (GND), U2.29_6 (GND), U2.29_7 (GND), U2.29_8 (GND), U2.29_9 (GND), U3.13 (GND), U4.1 (CTG), U4.4 (GND), U4.6 (QSTRT), U4.9 (EP)
GPIO8: R1.1, U2.10 (IO8)
I2C_PW: R1_PINH.2, R2-PINH.2, SENSOR2.2 (CSB), SENSOR2.6 (VDDIO), SENSOR2.8 (VDD), U2.17 (IO19)
INT_RTC: R1_PINH1.1, TP15.TP, U2.8 (IO0), U3.3 (SQW/!INT)
IO/BOOT: BOOT_BUTTON.3, BOOT_BUTTON.4, C6.1, R_BOOT.1, U2.15 (IO9)
IO/CHANGE: C10.1, CHANGE_BUTTON.3, CHANGE_BUTTON.4, R_CHANGE.1, U2.23 (IO15)
MISO: D12.2, J4.P7 (DAT0), R8.1, TP6.TP, U1.2 (DO(IO1)), U2.27 (IO2)
MOSI: D11.2, J1.14, J4.P3 (CMD), R7.1, TP7.TP, U1.5 (DI(IO0)), U2.7 (IO7)
unnamed: MCP73831.5 (PROG), R2_BAT.2
unnamed: C4.1, D3.2 (A), D4.1 (K)
unnamed: J2.A5, R2-USB1.2
unnamed: C1_BAT1.1, D2.1 (CATHODE), IC4.1 (VIN), IC4.3 (CE), Q1.2 (S)
unnamed: MCP73831.1 (STAT), R1_BAT.2
unnamed: CHG_LED.C, R1_BAT.1
unnamed: EPD_C1.1, J1.4
unnamed: EPD_C2.1, J1.5
unnamed: J2.B5, R2-USB.1
unnamed: EPD_C10.1, J1.22
unnamed: C_DELAY.1, IC1.5 (CT)
unnamed: C1.1, C2.1
unnamed: D7.1 (CATHODE), R_CAPACITOR.1
unnamed: EPD_C8.1, J1.20
unnamed: EPD_C11.1, J1.24
unnamed: EPD_C7.1, J1.19
unnamed: EPD_C6.1, J1.18
PREVGH: D5.1 (K), EPD_C9.1, J1.21
PREVGL: D4.2 (A), EPD_C12.1, J1.23
RESE: J1.3, Q3.2 (S), R3.2
RESE': R2.2, R3.1, SJ1.2
RESET: C5.1, IC1.1 (VOUT), RESET_BUTTON.3, RESET_BUTTON.4, R_RESET.1, U2.3 (EN)
RTC_RST: U2.16 (IO18), U3.4 (!RST)
RX: TP2.TP, U2.24 (RXD0/GPIO17)
SCK: D10.2, J1.13, J4.P5 (CLK), R6.1, TP8.TP, U1.6 (CLK), U2.6 (IO6)
SCL: J3.4, R2-PINH.1, SENSOR2.4 (SCK), U2.20 (IO22), U3.16 (SCL), U4.7 (SCL)
SDA: J3.3, R1_PINH.1, SENSOR2.3 (SDI), U2.19 (IO21), U3.15 (SDA), U4.8 (SDA)
SRC: C4.2, D5.2 (A), L1.1, Q3.3 (D)
SS_SD: D8.2, J4.P2 (CD/DAT3), R10.1, U2.4 (IO4)
TX: TP1.TP, U2.25 (TXD0/GPIO16)
USB_D+: D1.1 (I/O1_1), U2.14 (IO13)
USB_D-: D1.3 (I/O2_1), U2.13 (IO12)
VBAT: C2_BAT.1, MCP73831.3 (VBAT), Q1.3 (D), TP3.TP, U4.2 (CELL), U4.3 (VDD)
VBUS: C1_BAT.1, C4_USB.1, C5_USB.1, CHG_LED.A, D1.5 (VBUS), D2.2 (ANODE), MCP73831.4 (VIN), PFMF.050.1.2, Q1.1 (G), R1_PWRUSB.2, TP14.TP
VRTC: C8.1, C10_SUPERCAP.2, R_CAPACITOR.2, U3.14 (VBAT)
VUSB: J2.A4, J2.A9, J2.B4, J2.B9, PFMF.050.1.1

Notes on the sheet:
USB C connector & ESD protection
LDO Voltage Regulator
SD Card
Display Type Selector
E-Paper Drive Circuit
Li-Po Battery Charging Controller
ESP32 C6
E-Paper Display Header
EPD Power
Environmental Sensor BME688
Voltage Supervisor + Reset & Boot / IO Button
Battery Charge Level
RTC Module DS3231SN
Test Pads
Qwiic / Stemma QT
SPI ESD Protection Lines
External NOR Flash 64MB
OpenBook Schematic

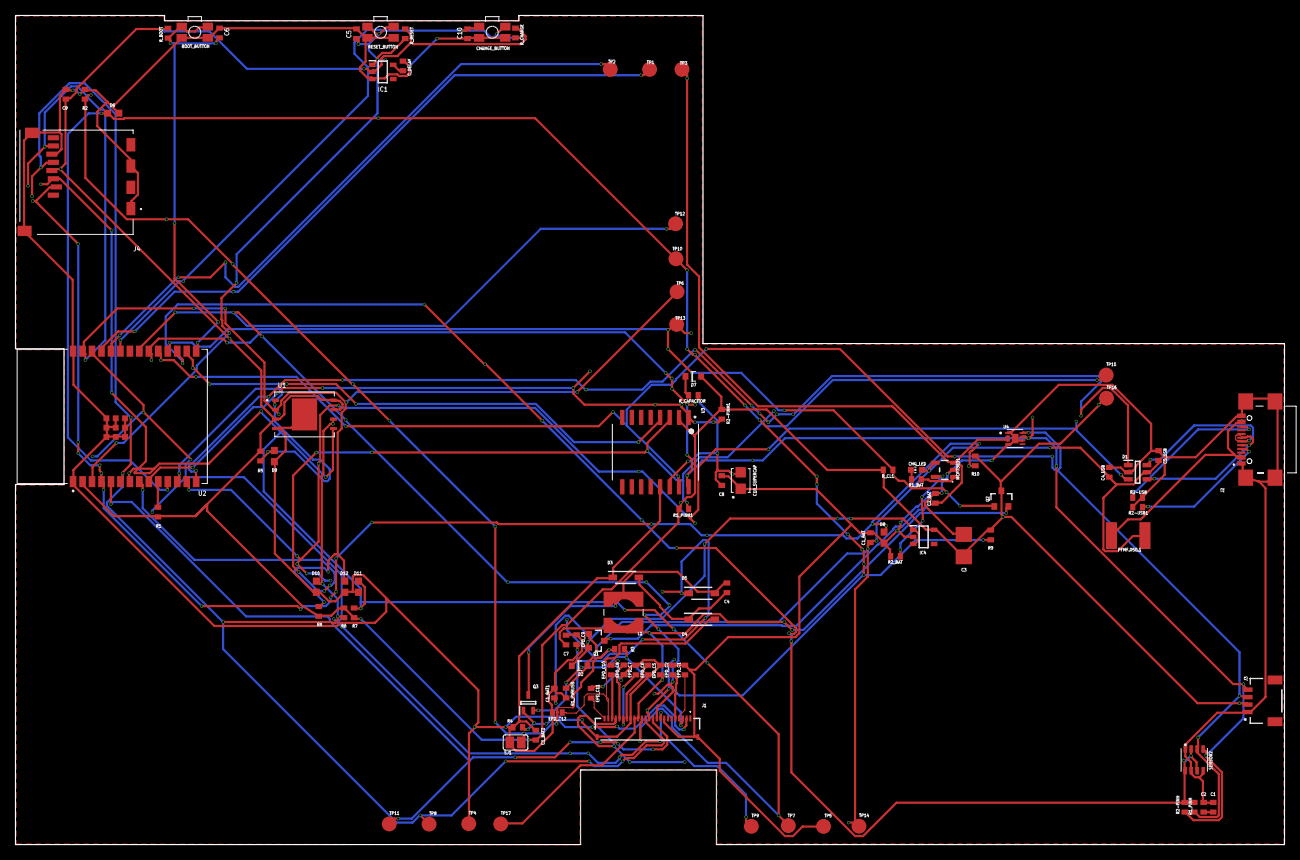
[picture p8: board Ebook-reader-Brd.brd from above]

Board: 2 copper layers, 170.2 x 111.2 mm, 103 parts (0 on the bottom side), 56 nets.

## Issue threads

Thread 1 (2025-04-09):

Schematic Warnings

alexiatsikri, 2025-04-09:
Din erorile aparute, trebuie sa o rezolvi pe aceasta: "No pins on net N$15".

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

Liniile care delimiteaza componentele nu trebuie sa fie pe layerul de net.

Closed 2025-04-15.

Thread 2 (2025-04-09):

Schematic #2

alexiatsikri, 2025-04-09:
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

In acelasi schematic ai folosit 2 package-uri diferite pentru GND (GND4 si SUPPLY2). Trebuie sa alegi unul si sa il folosesti in toata schema.

urecheandreea, 2025-04-15:
Desi sunt din 2 package-uri diferite , sunt tratate ca fiind parte din aceeasi retea logica.

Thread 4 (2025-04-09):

3D Design

alexiatsikri, 2025-04-09:
Am vazut ca nu ai placuta si display-ul bagate in carcasa. Asa se vede de jos (din bottom):
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

Ar trebui sa fie in interiorul ei, Openbook sa se vada pe dinafara.

Closed 2025-04-15.

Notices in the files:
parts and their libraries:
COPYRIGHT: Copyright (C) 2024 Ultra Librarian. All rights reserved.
